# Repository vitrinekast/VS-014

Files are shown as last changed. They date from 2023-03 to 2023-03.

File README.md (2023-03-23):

# VS-011
This VS is a digital tape delay, created using the Arduino nano. Due to memory limitations, only a limited delay length is possible (1900 ms), although you could optimize this.

The code and circuit are taken from [https://projecthub.arduino.cc/CesarSound/c4f2fdea-9035-44a8-9e2c-60ea6ff38159](CesarSound) and tweaked to taste. 

### Features
- Dry/wet knob
- set delay length (0 - 1900ms). The longer the delay, the more distorted the signal becomes
- Play audio signal reversed
- Overdub feature 

To make the VS-011, apart from the files in this repo, you'll need
- a videotape, preferably from your year of birth
- pin headers
- 2 audio jacks
- Arduino nano
- Material suitable to be laser-cut, <3mm thick
- 9V battery + battery clip
- 2 potentiometers
- 1 switch
- XXXX Resistors
- XXXX Capacitors
- XXXX 
- 2 button switches
- Apple magic keyboard

# Build instructions
Prepare the videotape to meet the following. For more info on VHS, see https://goughlui.com/the-vhs-corner/intro-inside-the-vhs-cassette-vcr/
- remove all screws (keep 'em) so all parts of the tape are accessible
- Remove and keep all the little loose parts and things 
- remove the so-called "top flap". You'll create a new one later.
- remove the transparent circular things from the white reels, try not to break the reels.
- Drill holes in the white reels, so a potentiometer will fit. This is a bit tricky and make sure not to saw in your hand doing so.
- Remove the aluminum strap from the front panel. Now, you can drill holes for the potentiometers.
- cut two holes for the buttons in the front panel. On the back panel, cut away some material so the buttons will fit on the inside as well.
- Cut away as much of the material on the top side, behind the removed top flap, as possible. This will house the electronics
- Cut away material on the left and right side, behind the removed top flap. Use `panel/VS-014_Side.dxf` as a guide, cut away material so the audio jack (bigger hole) will fit, and drill a hole for the bolt. The bolts will keep the new top flap connected to the tape.

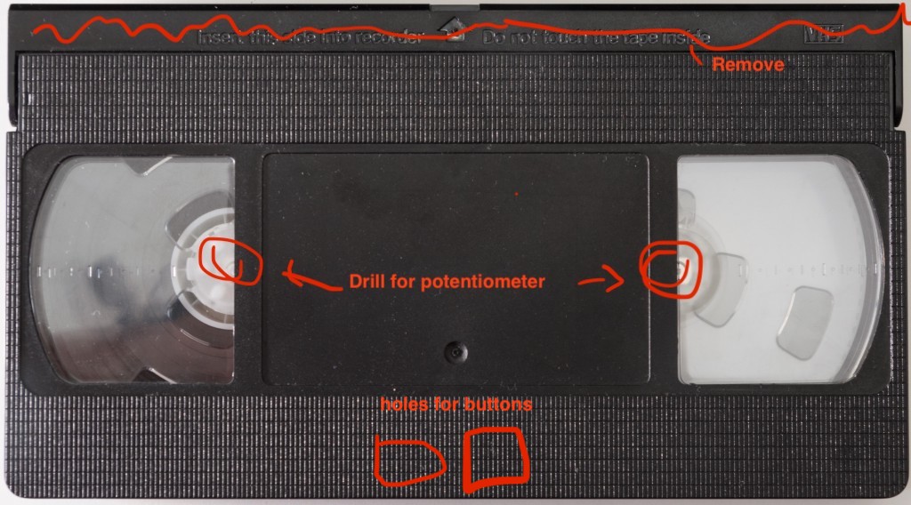
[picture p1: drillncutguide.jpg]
drill & cut guide


Now, your tape is stripped and ready for the new top flap

## Creating the top flap
Lasercut 1x front, 1x top, and 2x side (one is mirrored). If you need to alter dimensions, the fusion files are also included in the `panel` folder. Glue the front to the 2x sides using wood glue, but keep the top apart.

## Circuit
Prepare the schematic below using a Perfboard. Keep in mind the dimensions of the tape, everything still has to fit inside. See the image below of what goes where.

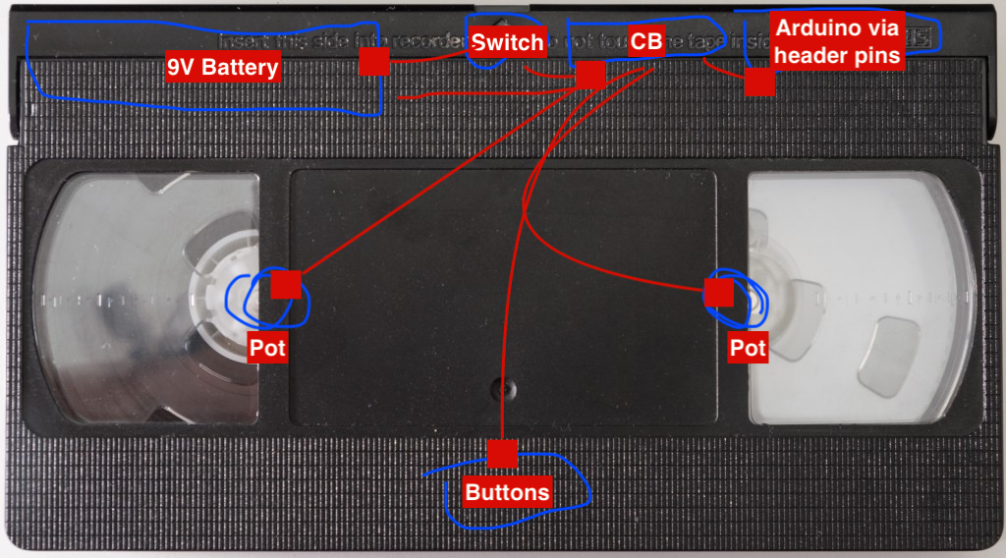
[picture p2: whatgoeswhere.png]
what goes where


Glue the created circuit board to the inside of the front panel. Connect the Arduino to the front panel using the header pins. Attach the switch, battery clip, and audio jacks, and connect everything according to the schematic.

Happy and tested? Now connect the top panel to the new flap, and put the 2 bolts in place. Time to play!

### Resources

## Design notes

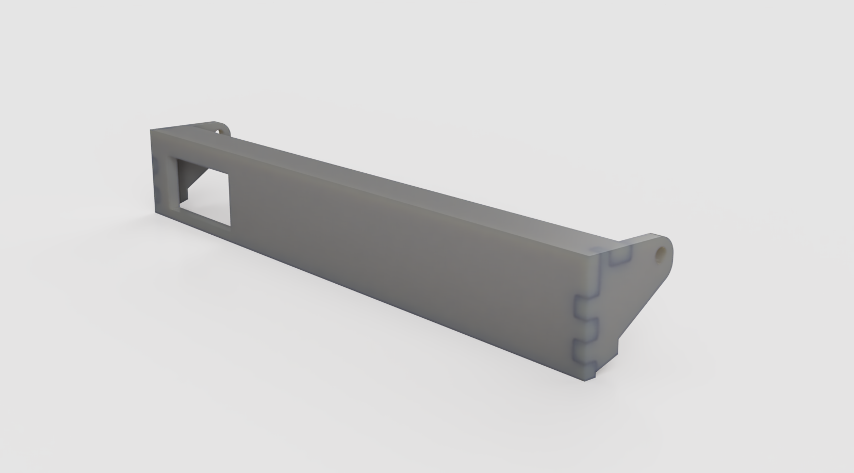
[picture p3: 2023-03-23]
panel/render.png

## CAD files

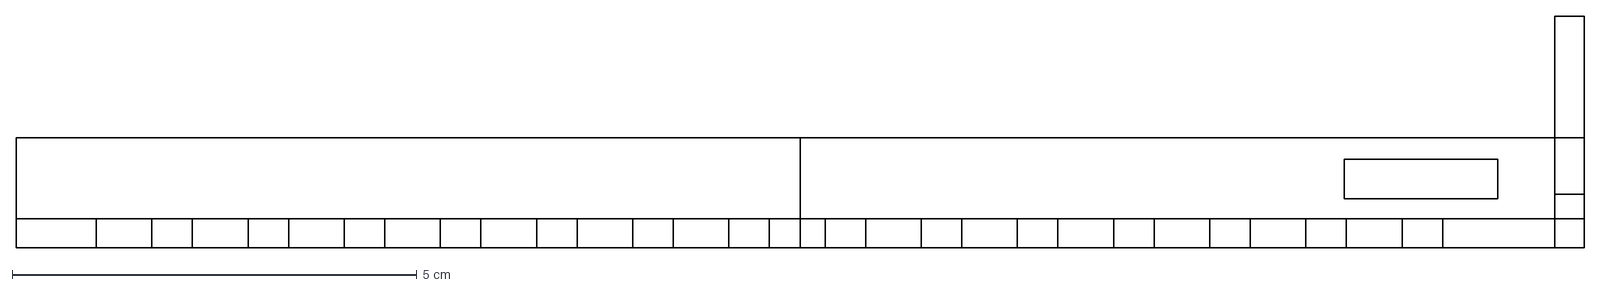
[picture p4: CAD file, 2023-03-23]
panel/VS-011.dxf
19.4 x 2.86 cm

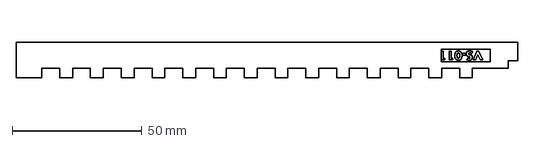
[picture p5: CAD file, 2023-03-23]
panel/VS-011_TOP.dxf
193.6 x 13.6 mm

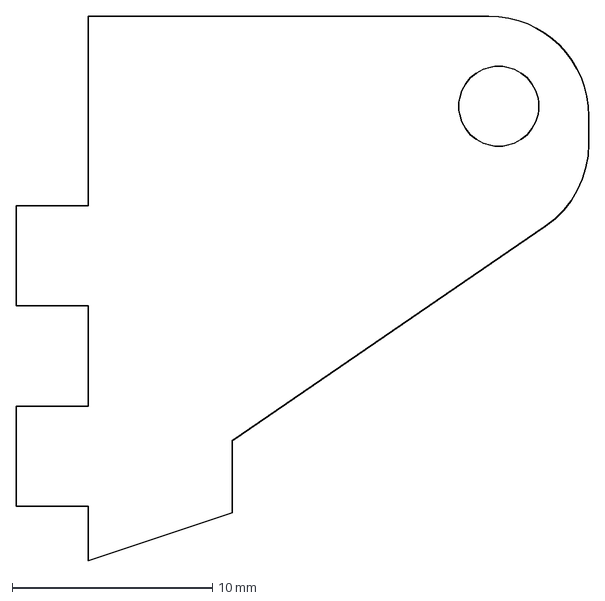
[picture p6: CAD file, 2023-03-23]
panel/VS-011-Side.dxf
28.6 x 27.2 mm

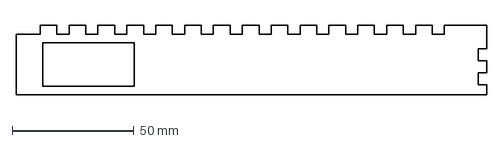
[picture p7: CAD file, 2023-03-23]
panel/VS-011_Front.dxf
193.6 x 28.4 mm

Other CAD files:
panel/VS-014 v7.f3d

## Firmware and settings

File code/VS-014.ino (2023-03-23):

/*****************************************************************************************************************************
  echoTrek - 8Bit Digital Delay / LO-FI Bitcrusher / Reverse Speech DSP Pedal Effects  for Guitar, Voice, Synths, etc.
  Works with Arduino UNO R3 / NANO / PRO MINI  - See the schematics for wiring details. By J. CesarSound - ver 1.0 - Jan/2021.
  
  Accessed From: https://projecthub.arduino.cc/CesarSound/c4f2fdea-9035-44a8-9e2c-60ea6ff38159
******************************************************************************************************************************/

#define audio_in A0
#define repeat_selector 9
#define rev_selector 10
#define delay_time_in A7

#define gran_len 100;
const unsigned int d_size = 1900;  //Delay memory buffer size
unsigned int val, d_val, d_time;
int i, j;
byte count = 2;
bool rev = 0;
bool gran = 0;
bool repeat = 0;
int granCount = 0;
char delay_data[d_size + 1] = { NULL };    //Delay  memory buffer
char delay_data_1[d_size + 1] = { NULL };  //Delay memory buffer


void setup() {
  pinMode(repeat_selector, INPUT_PULLUP);
  pinMode(rev_selector, INPUT_PULLUP);

  InitTimer1();               //Set up timer 1 for 16.384kHz
  setPwmFrequency(5, 1);      //function for setting PWM High frequency 62.475kHz on  pin D5
  analogReference(INTERNAL);  //Use 1.1v aref voltage.
  

  d_time = d_size;
}

void loop () {
  
}
void sampling() {
  d_time = map(analogRead(delay_time_in), 0, 1100, 0, d_size);
  val = map(analogRead(audio_in), 0, 900, 0, 255);
  if (digitalRead(rev_selector) == HIGH) {
    rev = 0;
  } else {
    rev = 1;
  }

  if (digitalRead(repeat_selector) == HIGH) {
    repeat = 0;
  } else {
    repeat = 1;
  }
  delay_sound();
  analogWrite(5, d_val);
}

void delay_sound() {
  if(gran) granCount++;
  
  if(gran && granCount > gran_len) {
    i = random(0, d_size - gran_len);
    granCount = 0;
  }

  i = i + 1;
  if (i > d_time) i = 0;
  delay_data[i] = val;

  if (i == d_time) j = 0;
  if (!repeat) delay_data_1[i] = delay_data[i];
  else {
    if (delay_data_1[i] < delay_data[i]) {
      delay_data_1[i] = delay_data[i];
    }
  }
  j = j + 1;
  if (j > d_time) j = 0;
  if (!rev) d_val = delay_data_1[j];
  if (rev) d_val = delay_data_1[d_time - j];
}


//Set  up timer 1 for 16.384kHz (975)
void InitTimer1() {
  cli();        //Disable global  interrupts
  TCCR1A = 0;   //Reset Timer 1 Counter Control Register A
  TCCR1B = 0;   //Reset Timer 1 Counter Control Register B
  TCNT1 = 0;    //initialize counter  value to 0
  OCR1A = 975;  //Set Timer 1 to desired frequency: 16384Hz (16,000,000  / 16384) - 1 = 975
  //Turn on CTC (clear timer on compare match) mode:
  TCCR1B |= (1 << WGM12);
  TCCR1B |= (1 << CS10);    //CS10 Prescalar = 1 (no prescalar  used); CS11 Prescalar = 8
  TIMSK1 |= (1 << OCIE1A);  //Enable timer interrupt
  sei();                    //Enable interrupts
}

ISR(TIMER1_COMPA_vect) {
  sampling();
}

//PWM  62.475kHz high frequency DAC for pins 5 & 6 (others are 32k)
void setPwmFrequency(int pin, int divisor) {
  byte mode;
  if (pin == 5 || pin == 6 || pin == 9 || pin == 10) {
    switch (divisor) {
      case 1: mode = 0x01; break;
      case 8: mode = 0x02; break;
      case 64: mode = 0x03; break;
      case 256: mode = 0x04; break;
      case 1024: mode = 0x05; break;
      default: return;
    }
    if (pin == 5 || pin == 6) {
      TCCR0B = TCCR0B & 0b11111000 | mode;
    } else {
      TCCR1B = TCCR1B & 0b11111000 | mode;
    }
  } else if (pin == 3 || pin == 11) {
    switch (divisor) {
      case 1: mode = 0x01; break;
      case 8: mode = 0x02; break;
      case 32: mode = 0x03; break;
      case 64: mode = 0x04; break;
      case 128: mode = 0x05; break;
      case 256: mode = 0x06; break;
      case 1024: mode = 0x07; break;
      default: return;
    }
    TCCR2B = TCCR2B & 0b11111000 | mode;
  }
}

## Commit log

2023-03-23 add dxf files
    [VS-011-Side.dxf, VS-011_Front.dxf, VS-011_TOP.dxf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]
2023-03-23 add render
    [VS-011.dxf]
